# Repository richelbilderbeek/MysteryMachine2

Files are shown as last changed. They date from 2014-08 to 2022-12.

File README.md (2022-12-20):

# MysteryMachine2

MysteryMachine2 schematic.

MysteryMachine2 is a more complex variant of [MysteryMachine](https://github.com/richelbilderbeek/MysteryMachine).

MysteryMachine2 is developed by (alphabetic list):

  * Nora Migdad
  * Richel Bilderbeek
  * Willy Bakker

## 2017-07-30 build

Built by Carmen IJsebaart (drilling, glueing, soldering) and Richel Bilderbeek (coordinating, drilling, glueing, soldering, testing).

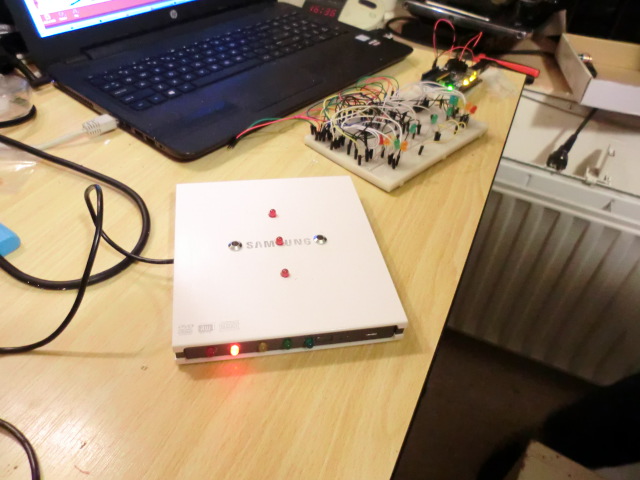
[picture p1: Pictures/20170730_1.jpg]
MysteryMachine 2 1


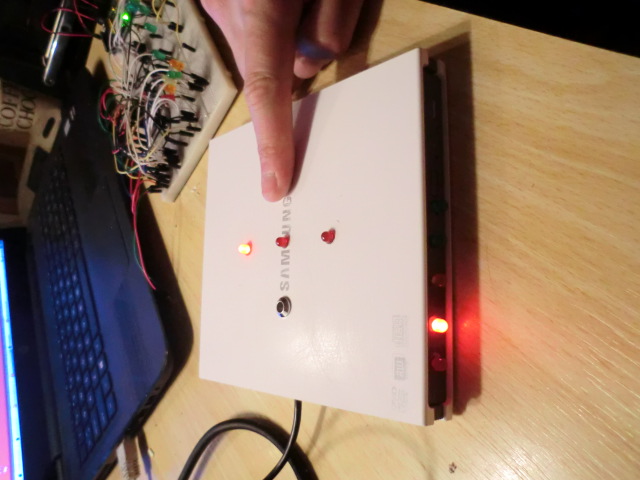
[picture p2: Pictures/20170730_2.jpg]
MysteryMachine 2 2


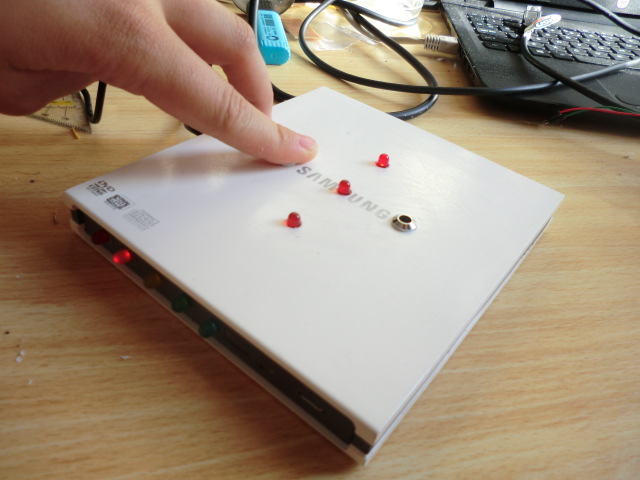
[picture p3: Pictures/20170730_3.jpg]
MysteryMachine 2 3


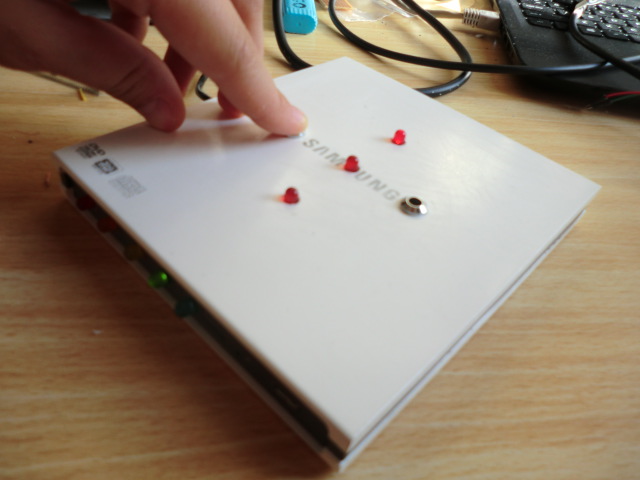
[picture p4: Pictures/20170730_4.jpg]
MysteryMachine 2 4


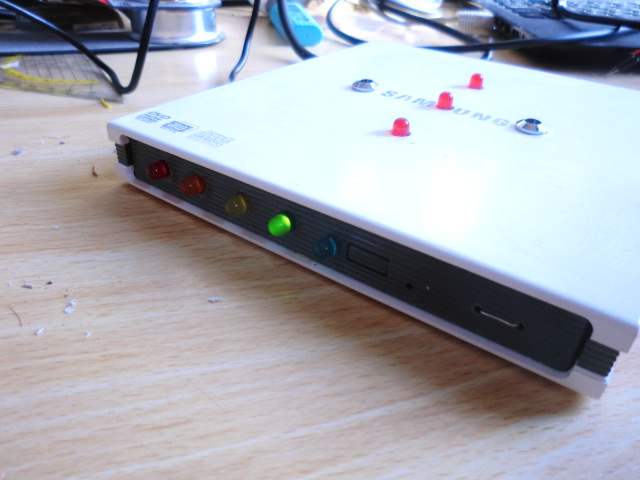
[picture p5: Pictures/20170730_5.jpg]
MysteryMachine 2 5


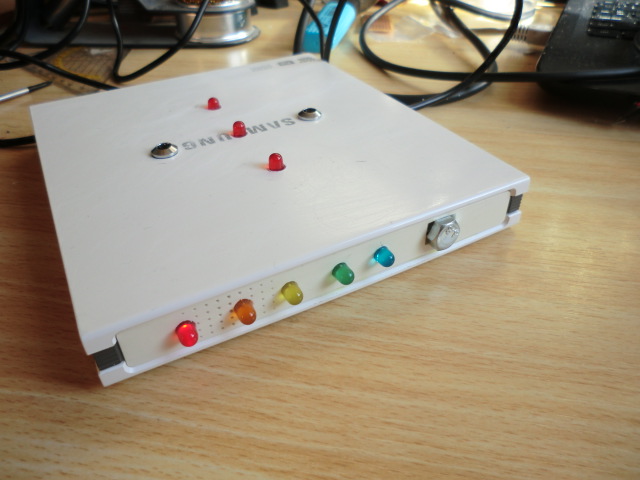
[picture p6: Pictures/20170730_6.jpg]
MysteryMachine 2 6


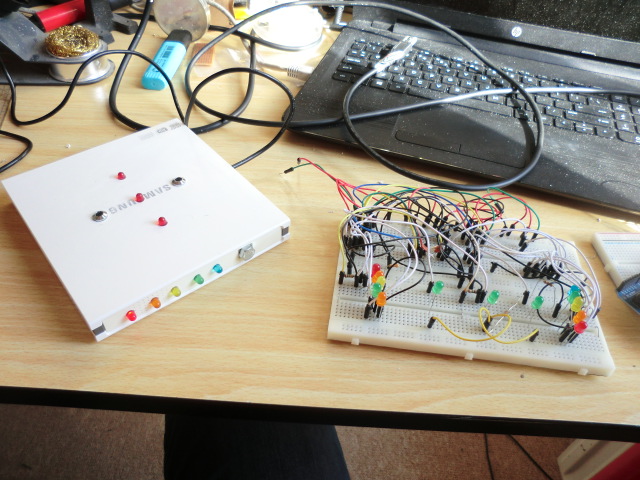
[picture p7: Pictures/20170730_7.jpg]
MysteryMachine 2 7


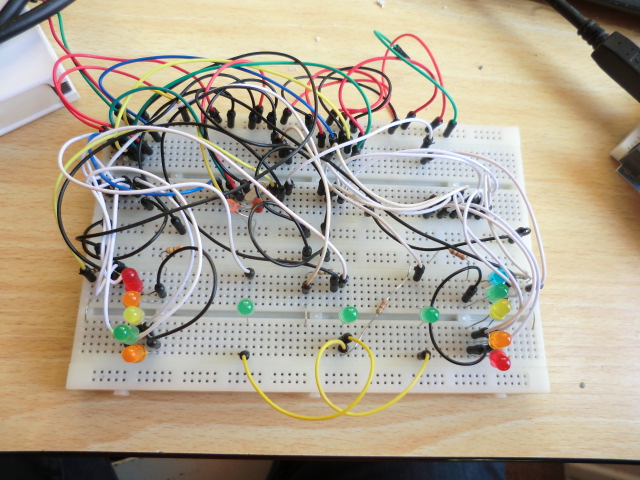
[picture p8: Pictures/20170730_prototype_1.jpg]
MysteryMachine 2 prototype 1 (without chips)


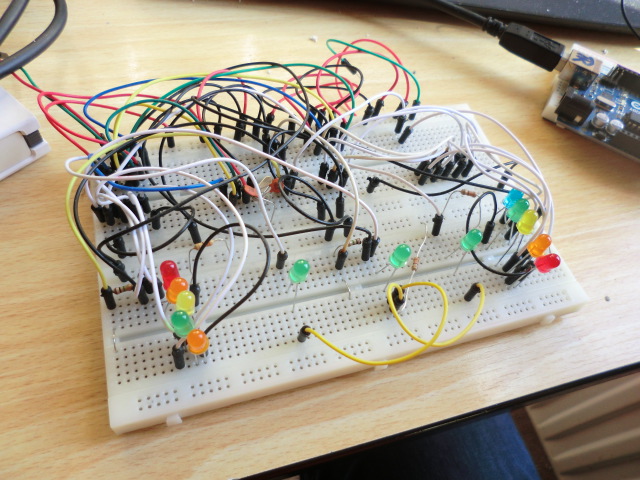
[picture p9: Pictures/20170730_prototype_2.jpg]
MysteryMachine 2 prototype 2 (without chips)


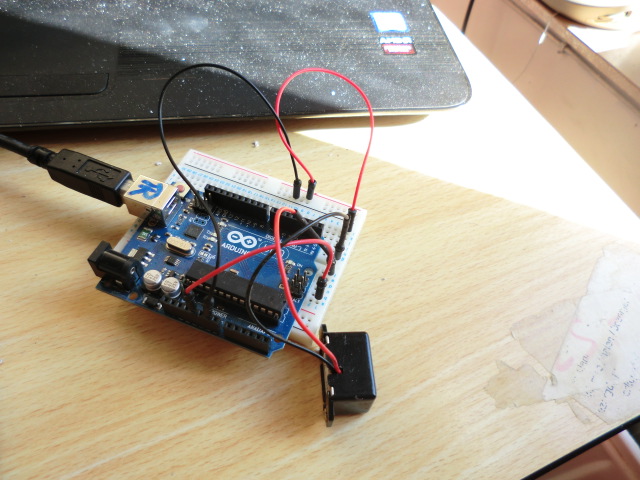
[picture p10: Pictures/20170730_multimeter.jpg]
MysteryMachine 2 replacement multimeter


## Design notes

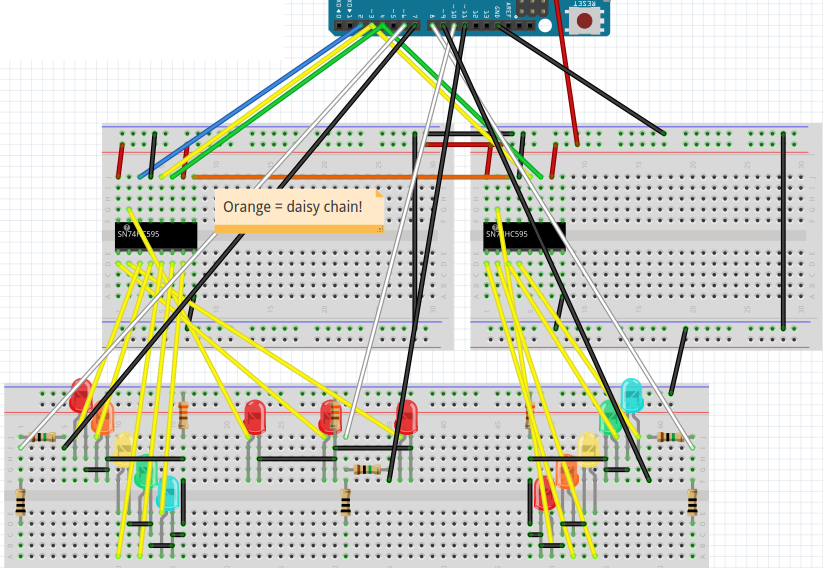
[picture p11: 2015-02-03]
CapacitiveSensor/MysteryMachine2.png

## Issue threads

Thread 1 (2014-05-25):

Add schematic

richelbilderbeek, 2014-05-25:
By Nora & Willy.

richelbilderbeek, 2021-04-21:
Too long ago, let's close!

Closed 2021-04-21.

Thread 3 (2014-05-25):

Add two reed switches

richelbilderbeek, 2014-05-25:
Add two reed switches, one for each side. If it is closed, the top LED at that side will always emit when the pushbuttons are pressed

richelbilderbeek, 2021-04-21:
Too long ago, let's close!

Closed 2021-04-21.

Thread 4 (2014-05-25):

Use two push buttons

richelbilderbeek, 2014-05-25:
Use two push buttons (one per side) instead of one. One of the top LEDs will emit when both are pressed.

richelbilderbeek, 2021-04-21:
Too long ago, let's close!

Closed 2021-04-21.

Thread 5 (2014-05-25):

Use two toggle buttons

richelbilderbeek, 2014-05-25:
Use two toggle buttons (one per side) for the power. Use a hotel schematic: if one changes position, the machine turns from on to off or vice versa.

richelbilderbeek, 2021-04-21:
Too long ago, let's close!

Closed 2021-04-21.

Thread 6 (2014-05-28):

Create BOM

richelbilderbeek, 2014-05-28:
- 13x [330 Ohm resistance](http://www.okaphone.com/artikel.asp?id=466781)
- 1x [Bare bone kit](http://www.okaphone.com/artikel.asp?id=476081) (has  1x [Atmel microcontroler](http://www.okaphone.com/artikel.asp?id=468509) and 1x [IC foot 28 pin](http://www.okaphone.com/artikel.asp?id=426394))
  - 2x 1MC rotary switch with 12 states
  - 2x [knob for rotary switches](http://www.okaphone.com/artikel.asp?id=450648)
  - 2x [push button](http://www.okaphone.com/artikel.asp?id=450013)
  - 2x [toggle switch](http://www.okaphone.com/artikel.asp?id=451204)
  - 1x [battery holder](http://www.okaphone.com/artikel.asp?id=1365)
  - 13x [LED clip 5 mm](http://www.okaphone.com/artikel.asp?id=432805)
  - 2x [LED green 5 mm](http://www.okaphone.com/artikel.asp?id=453127)
  - 5x [LED red 5 mm](http://www.okaphone.com/artikel.asp?id=422565)
  - 2x [LED yellow 5 mm](http://www.okaphone.com/artikel.asp?id=422563)
  - 2x [LED orange 5 mm](http://www.okaphone.com/artikel.asp?id=454001)
  - 2x LED other color
  - 1x [Double sided photosensitive circuit board](http://www.okaphone.com/artikel.asp?id=412554)

richelbilderbeek, 2021-04-21:
Too long ago, let's close!

Closed 2021-04-21.

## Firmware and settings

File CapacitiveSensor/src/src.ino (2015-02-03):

  /*
  MysteryMachine2
  (C) 2015 Richel Bilderbeek

*/
/*

Description chip SN74HC595:

 16 15 14 13 12 11 10 9
 |  |  |  |  |  |  |  |
 +--+--+--+--+--+--+--+
 |>                   |
 +--+--+--+--+--+--+--+
 |  |  |  |  |  |  |  |
 1  2  3  4  5  6  7  8

 Official pin names:

 1: Q2
 2: Q3
 3: Q4
 3: Q5
 5: Q6
 6: Q7
 7: Q8 
 8: GND
 9: QH*: for daisy chaining, unused otherwise
 10: SRCLR* (to 5V)
 11: SRCLK (to clock pin)
 12: RCLK (to latch pin)
 13: OE* (to GND)
 14: SER (to data pin)
 15: Q1
 16: VCC (naar 5V)


First shift register:

 16 15 14 13 12 11 10 9
 |  |  |  |  |  |  |  |
 +--+--+--+--+--+--+--+
 |>                   |
 +--+--+--+--+--+--+--+
 |  |  |  |  |  |  |  |
 1  2  3  4  5  6  7  8

 Verbindingen:

 1: to LED_M2
 2: to LED_M3
 3: LED 4
 3: LED 5
 5: LED 6
 6: LED 7
 7: LED 8 
 8: GND
 9: naar pin 14 van het tweede shift register (dit is de daisy chain verbinding)
 10: naar 5V
 11: naar D4: clock pin
 12: naar D3: latch pin
 13: naar GND
 14: naar D2: data pin
 15: to LED_M1
 16: naar 5V

Tweede shift register:

 16 15 14 13 12 11 10 9
 |  |  |  |  |  |  |  |
 +--+--+--+--+--+--+--+
 |>                   |
 +--+--+--+--+--+--+--+
 |  |  |  |  |  |  |  |
 1  2  3  4  5  6  7  8

 Verbindingen:

 1: LED 10
 2: LED 11
 3: LED 12
 3: LED 13
 5: LED 14
 6: LED 15
 7: LED 816
 8: GND
 9: wordt niet gebruikt
 10: naar 5V
 11: naar D4: clock pin
 12: naar D3: latch pin
 13: naar GND
 14: naar pin 9 van eerste shift register (dit is de daisy chain verbinding)
 15: naar LED 9
 16: naar 5V

  Connecting the three sensors:
  
  6              7 
  |  +--------+  |
  +--+ R      +--+
  |  +--------+
  |
  X
  
  8              9 
  |  +--------+  |
  +--+ R      +--+
  |  +--------+
  |
  X

  10             11 
  |  +--------+  |
  +--+ R      +--+
  |  +--------+
  |
  X

  6,8,10: sensor pins
  7,9,11: helper pins
  R: resistance of at least 1 Mega-Ohm (brown-black-green-gold)
  X: place to touch wire

*/

#include <CapacitiveSensor.h>

const int datapin  = 2;
const int latchpin = 3;
const int clockpin = 4;

const int pin_sensor1 =  6;
const int pin_helper1 =  7;
CapacitiveSensor sensor1 
  = CapacitiveSensor(pin_helper1,pin_sensor1);        
const int pin_sensor2 =  8;
const int pin_helper2 =  9;
CapacitiveSensor sensor2 
  = CapacitiveSensor(pin_helper2,pin_sensor2);        

const int pin_sensor3 = 10;
const int pin_helper3 = 11;
CapacitiveSensor sensor3 
  = CapacitiveSensor(pin_helper3,pin_sensor3);        

//Which of player 1's LEDs is active?
int p1 = 0;
//Which of player 2's LEDs is active?
int p2 = 0;

const bool debug = true;

void setup() 
{
  Serial.begin(9600);
  pinMode(latchpin, OUTPUT);
  pinMode(clockpin, OUTPUT);
  pinMode(datapin , OUTPUT);
}

void loop() 
{
  //The higher 'samples' is set, the more accurate the sensors measure
  const int samples = 30;

  //Measure the capacitive sensors
  const int r1 = sensor1.capacitiveSensor(samples);
  const int r2 = sensor2.capacitiveSensor(samples);
  const int r3 = sensor3.capacitiveSensor(samples);

  if (debug)
  {
    //Show the values in the Serial Monitor
    Serial.print(r1);
    Serial.print(" ");
    Serial.print(r2);
    Serial.print(" ");
    Serial.println(r3);
  }

  //The threshold value, which determines the sensitivity of the sensors
  // - too low: the program will think more often there is a touch, possibly even when you do not touch
  // - too high: the program will think less often there is a touch, possibly even when you do touch 
  const int t = 100;
  
  //Respond to touches
  if (r1 >= t) { p1 = (p1 + 1) % 5; }
  if (r2 >= t) { p2 = (p2 + 1) % 5; }
  const bool mid_pressed = r3 >= t;
  const int pm = CalcMidPin(p1,p2);

  ShowState(p1,p2,mid_pressed ? pm : -1);

  delay(100);
}

//0: mid pin at side 1
//1: mid pin at center
//2: mid pin at side 2
int CalcMidPin(const int p1, const int p2)
{
  if (p1 == p2) return 1;
  return (10 + p1 - p2) % 2 == 0 ? 0 : 2;
}

//s1: side 1 state
//s2: side 2 state
//mid: mid state, if mid == -1, then no center LED will be on
void ShowState(const int s1, const int s2, const int mid)
{
  const int b1 = 1 << s1;  
  const int b2 = 1 << s2;  
  //if mid == -1, then no center LED will be on
  const int bm = mid >= 0 ? 1 << mid : 0;
  const int value = (b2 << 8) + (b1 << 3) + bm;
  ShowBinary(value);
}

void ShowBinary(const int value) 
{
  //Start met schrijven
  digitalWrite(latchpin,LOW);

  //Bereken wat te schrijven
  // (dit moet in twee keer: een keer per shift register)
  const int high_value = value / 256;
  const int low_value  = value % 256;

  //Schrijf naar de shift registers
  //(opmerking: mocht je toch maar een shift register aansluiten,
  // dan wordt de high_value gewoon overschreven door de low_value,
  // oftewel: je ziet dan enkel de low_value)
  WriteToShiftRegister(high_value); 
  WriteToShiftRegister(low_value);

  //Klaar met schrijven
  digitalWrite(latchpin,HIGH);
}

void WriteToShiftRegister(const byte value) 
{
  // This shifts 8 bits out MSB first, 
  //on the rising edge of the clock,
  //clock idles low

  //prepare shift register for bit shifting
  digitalWrite(datapin, LOW);
  digitalWrite(clockpin, LOW);

  for (int i=7; i>=0; i--)  
  {
    digitalWrite(clockpin, 0);

    //if the value passed to myDataOut and a bitmask result 
    // true then... so if we are at i=6 and our value is
    // %11010100 it would the code compares it to %01000000 
    // and proceeds to set pinState to 1.
    //Sets the pin to HIGH or LOW depending on pinState
    digitalWrite(datapin, value & (1<<i) ? HIGH : LOW);
    //register shifts bits on upstroke of clock pin  
    digitalWrite(clockpin, HIGH);
    //zero the data pin after shift to prevent bleed through
    digitalWrite(datapin, LOW);
  }

  //stop shifting
  digitalWrite(clockpin, LOW);
}

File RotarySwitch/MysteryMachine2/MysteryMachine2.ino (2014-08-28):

//The pins that measure which position rotary switch 1 and 2 have
const int pins_input_1[] = {A0,A1,A2,A3,A4};
const int pins_input_2[] = {8,9,10,11,12};
const int n_inputs_1{5};
const int n_inputs_2{5};

//The pins to power the to leds
const int pins_led_top[] = {2,3,4};
const int n_leds_top{3};

void setup()
{
  for (int i{0}; i!=n_inputs_1; ++i) 
  { 
    pinMode(pins_input_1[i],INPUT);
  }
  for (int i{0}; i!=n_inputs_2; ++i) 
  { 
    pinMode(pins_input_2[i],INPUT);
  }
  for (int i{0}; i!=n_leds_top; ++i) 
  { 
    pinMode(pins_led_top[i],OUTPUT);
  }
}

int GetInput1()
{
  for (int i{0}; i!=n_inputs_1; ++i) 
  { 
    if (digitalRead(pins_input_1[i])) { return i; }
  }
  return -1;
}

int GetInput2()
{
  for (int i{0}; i!=n_inputs_2; ++i) 
  { 
    if (digitalRead(pins_input_2[i])) { return i; }
  }
  return -1;
}

void loop()
{
  const int a{GetInput1()};  
  const int b{GetInput2()};  
  if (a == -1 || b == -1) return;
  const int d{abs(a-b)};
  digitalWrite(pins_led_top[0],d == 1 || d == 3 ? HIGH : LOW);
  digitalWrite(pins_led_top[1],d == 0 ? HIGH : LOW);
  digitalWrite(pins_led_top[2],d == 2 || d == 4 ? HIGH : LOW);
  delay(100);
}

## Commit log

2014-05-28 Initial schemetic
    [MysteryMachine2.fzz]
2014-06-02 Now on one breadboard, has hotel switch
    [MysteryMachine2.fzz]
2014-08-24 Fixed and simplified schematic
    [MysteryMachine2.fzz]
2014-08-28 Improved schematic and routing
    [MysteryMachine2.fzz]
2014-08-28 Added bare-bone version
    [MysteryMachine2.fzz]
2015-02-10 Improved schematics
    [MysteryMachine2.fzz, MysteryMachine2Standalone.fzz]
